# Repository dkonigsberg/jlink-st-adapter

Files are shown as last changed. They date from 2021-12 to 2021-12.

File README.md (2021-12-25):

# J-Link to STDC14 Adapter Board

This repository contains the [KiCad](http://kicad.org/) project
with the complete circuit schematics and PCB layout for an adapter
board used to connect cables designed for the STDC14 connector from
the [ST-Link v3](https://www.st.com/en/development-tools/stlink-v3set.html)
programmer to the port on a [Segger J-Link](https://www.segger.com/products/debug-probes/j-link/)
programmer.

Since the J-Link pinouts for SWD and JTAG modes are not directly
compatible, jumpers have been added for switching between them.
Also, since the J-Link's Virtual COM Port feature does not work
with JTAG mode, it has also been brought out to a pin header
so it can be connected to a serial adapter if desired.

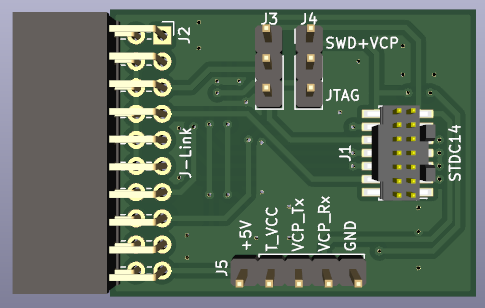
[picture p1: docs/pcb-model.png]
Board


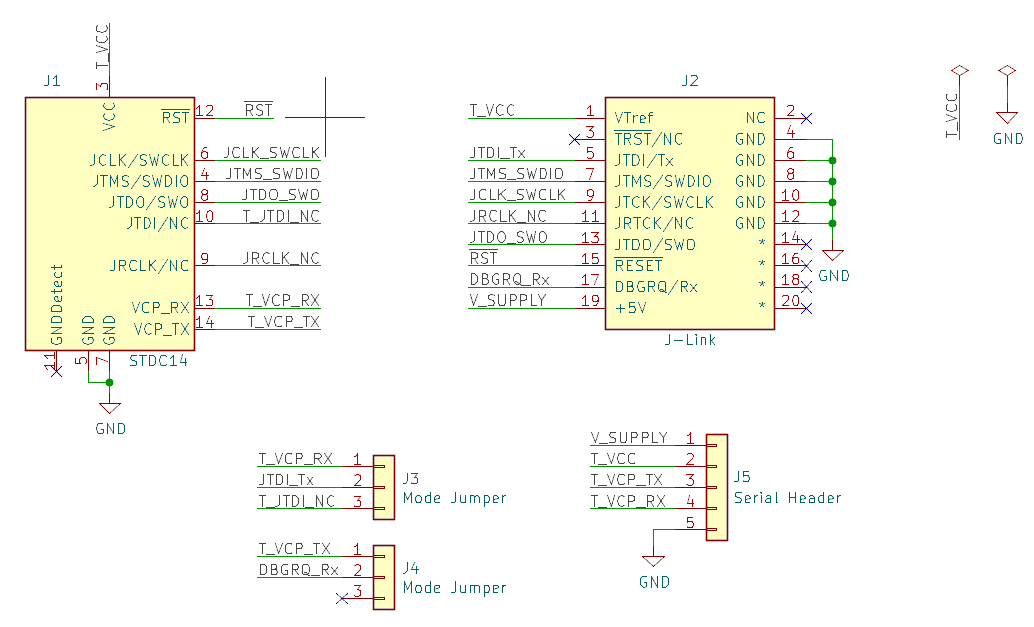
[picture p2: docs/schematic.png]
Schematic


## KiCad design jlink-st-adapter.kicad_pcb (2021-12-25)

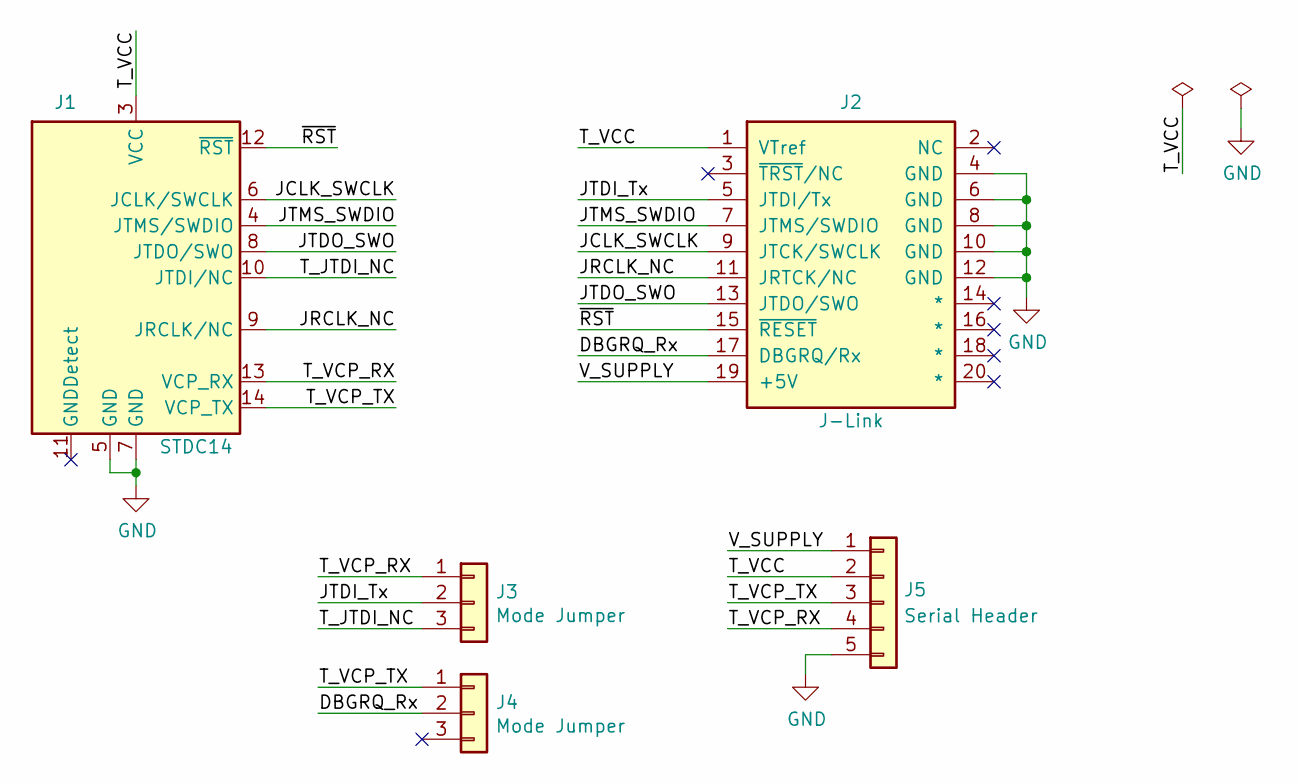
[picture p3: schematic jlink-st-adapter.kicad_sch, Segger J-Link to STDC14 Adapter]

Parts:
J1: STDC14; Samtec_FTSH-107-01-L-DV-K-A_2x07_P1.27mm; Manufacturer PN FTSH-107-01-L-DV-K-A
J2: J-Link; PinSocket_2x10_P2.54mm_Horizontal_Overhang; Manufacturer PN SFH11-PBPC-D10-RA-BK
J3, J4: Mode Jumper; PinHeader_1x03_P2.54mm_Vertical
J5: Serial Header; PinHeader_1x05_P2.54mm_Vertical

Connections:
/DBGRQ_Rx: J2.17 (DBGRQ/Rx), J4.2
/JCLK_SWCLK: J1.6 (JCLK/SWCLK), J2.9 (JTCK/SWCLK)
/JRCLK_NC: J1.9 (JRCLK/NC), J2.11 (JRTCK/NC)
/JTDI_Tx: J2.5 (JTDI/Tx), J3.2
/JTDO_SWO: J1.8 (JTDO/SWO), J2.13 (JTDO/SWO)
/JTMS_SWDIO: J1.4 (JTMS/SWDIO), J2.7 (JTMS/SWDIO)
/T_JTDI_NC: J1.10 (JTDI/NC), J3.3
/T_VCC: J1.3 (VCC), J2.1 (VTref), J5.2
/T_VCP_RX: J1.13 (VCP_RX), J3.1, J5.4
/T_VCP_TX: J1.14 (VCP_TX), J4.1, J5.3
/V_SUPPLY: J2.19 (+5V), J5.1
/~RST: J1.12 (~RST), J2.15 (~RESET)
GND: J1.5 (GND), J1.7 (GND), J2.4 (GND), J2.6 (GND), J2.8 (GND), J2.10 (GND), J2.12 (GND), J5.5

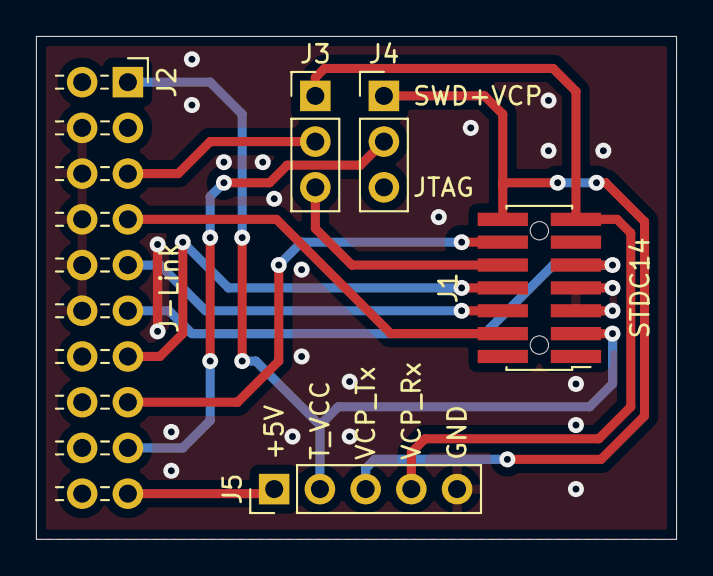
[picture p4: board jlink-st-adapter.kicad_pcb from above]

Board: 2 copper layers, 35.6 x 27.9 mm, 5 parts (0 on the bottom side), 13 nets.

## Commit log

2021-12-24 Initial commit for J-Link to STDC14 adapter
    [jlink-st-adapter.kicad_pcb, jlink-st-adapter.sch]
2021-12-25 New files and updates for KiCad 6.0
    [jlink-st-adapter.kicad_pcb, jlink-st-adapter.kicad_sch]
2021-12-25 Removed legacy files
    [jlink-st-adapter.sch]
